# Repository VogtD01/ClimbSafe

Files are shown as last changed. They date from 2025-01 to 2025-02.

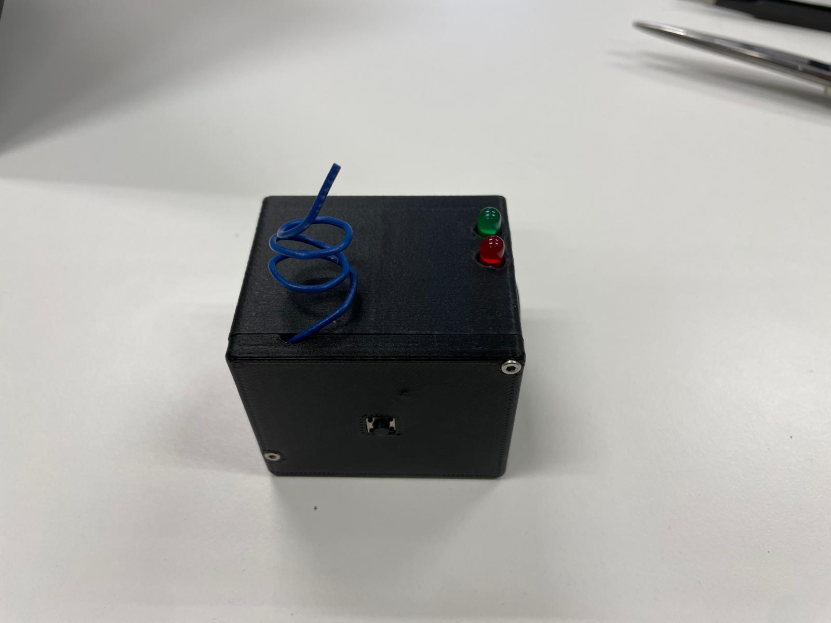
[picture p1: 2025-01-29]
Präsentation_Diagramme/Bilder/IMG-20250129-WA0006.jpg

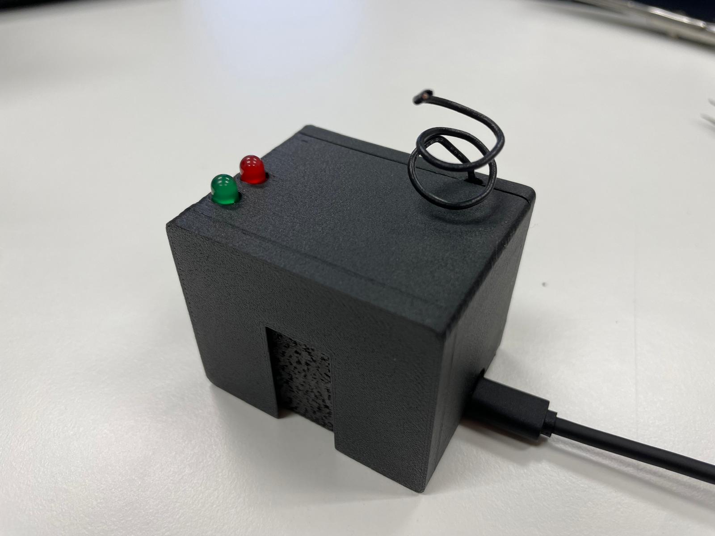
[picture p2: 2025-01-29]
Präsentation_Diagramme/Bilder/IMG-20250129-WA0011.jpg

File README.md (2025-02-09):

## Climbsafe 

ClimbSafe ist ein innovatives Sicherheitssystem für das Mehrseillängenklettern, das mithilfe von zwei ESP32-Mikrocontrollern und einem LoRa-Funkmodul eine zuverlässige Kommunikation zwischen Kletterpartnern ermöglicht. Zusätzlich integriert das System einen IMU-Sensor zur Sturzerkennung, um die Sicherheit beim Klettern zu verbessern.

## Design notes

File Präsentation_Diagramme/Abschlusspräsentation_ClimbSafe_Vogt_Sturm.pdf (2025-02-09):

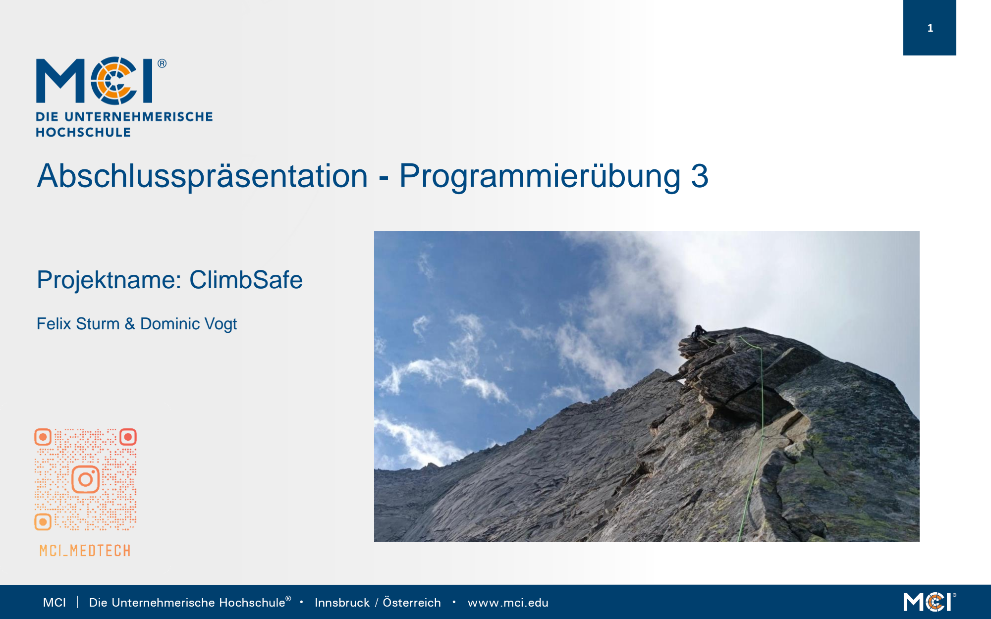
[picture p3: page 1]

1

# Abschlusspräsentation - Programmierübung 3

## Projektname: ClimbSafe

Felix Sturm & Dominic Vogt

2

## Ablauf - Mehrseillängenklettern

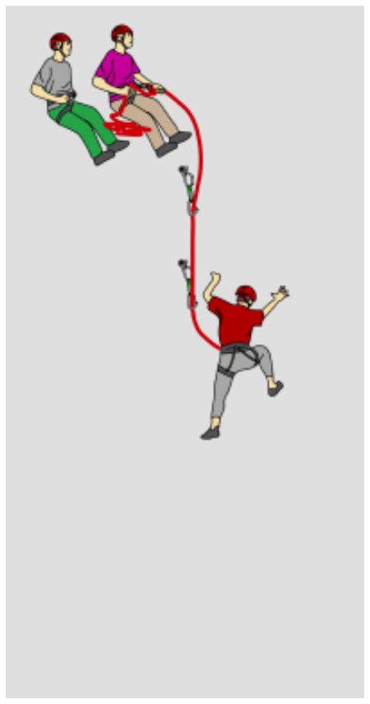
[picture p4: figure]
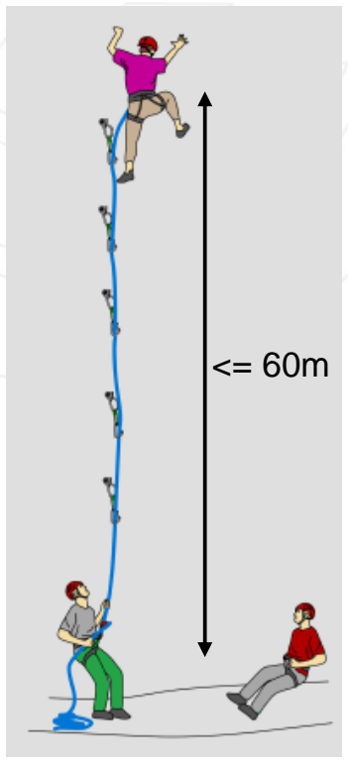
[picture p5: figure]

Vorstieg | Nachstieg
- Vorstieg

− Person 1 klettert
− Person 2 sichert Person 1
- Standplatzbau

− Person 1 baut Standplatz

- Nachstieg

− Person 1 sichert Person 2 − Person 2 klettert

3

## Problem - Mehrseillängenklettern

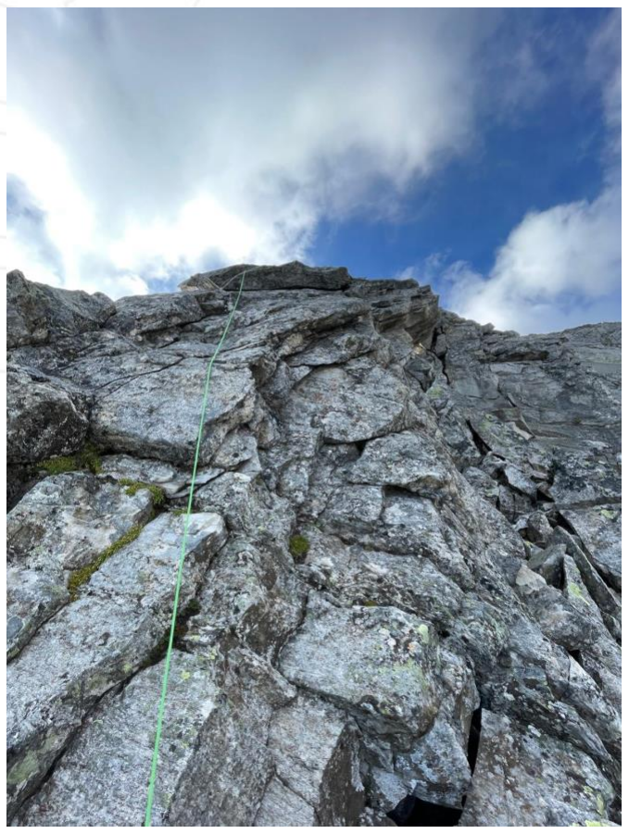
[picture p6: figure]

- Kommunikation eingeschränkt

− Überhang
− Nebel
− Wind
− …
- Bisherige Lösung:

Seilziehen

- Neue Lösung:

− Einfaches Kommunikationssystem mit Button, Piezo und LEDs

## Problem - Lösungsansatz

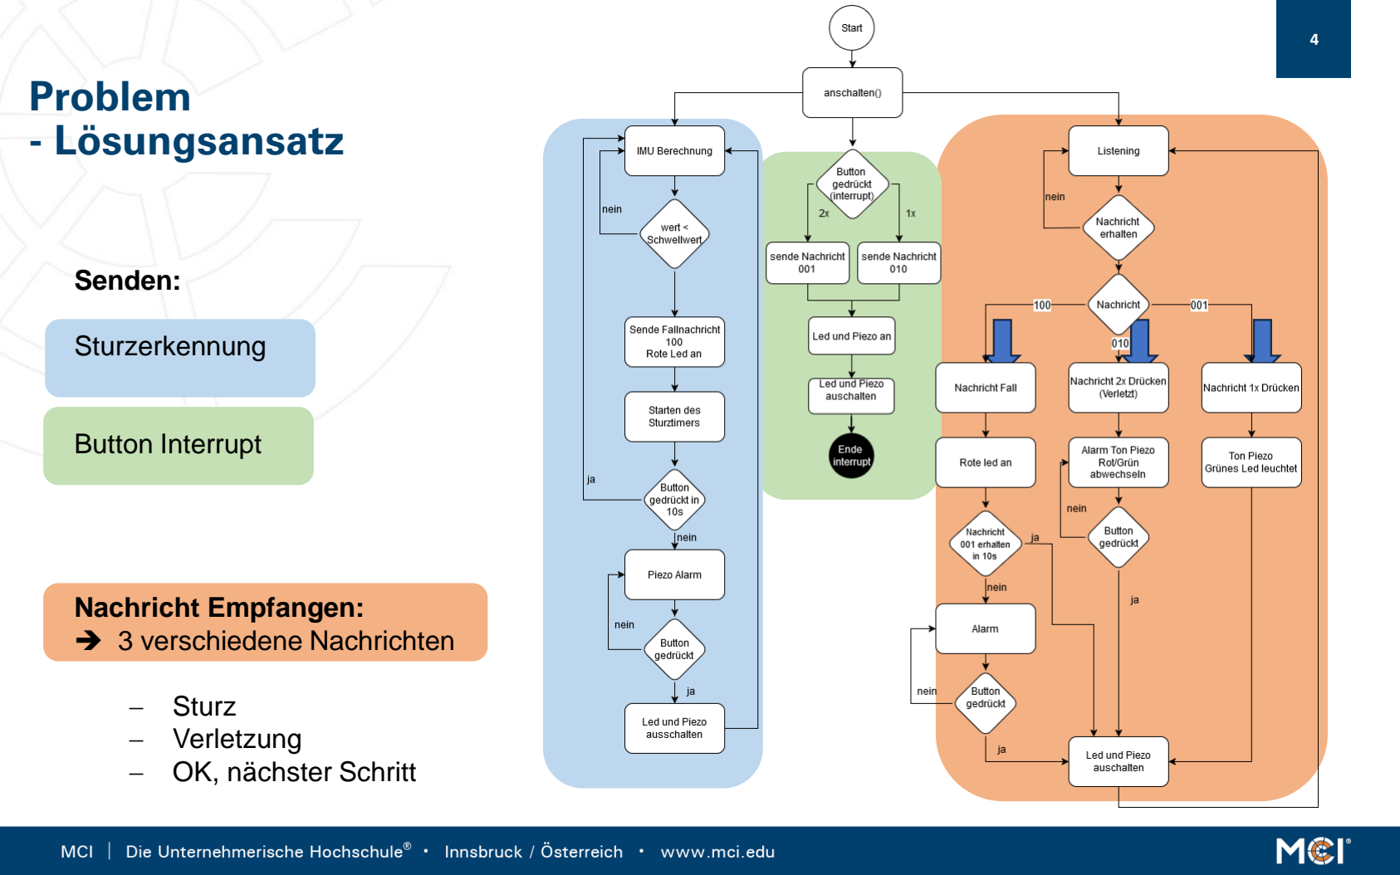
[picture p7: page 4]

4

Senden:

Sturzerkennung

Button Interrupt

Nachricht Empfangen: ➔ 3 verschiedene Nachrichten − Sturz − Verletzung − OK, nächster Schritt

# Systemübersicht

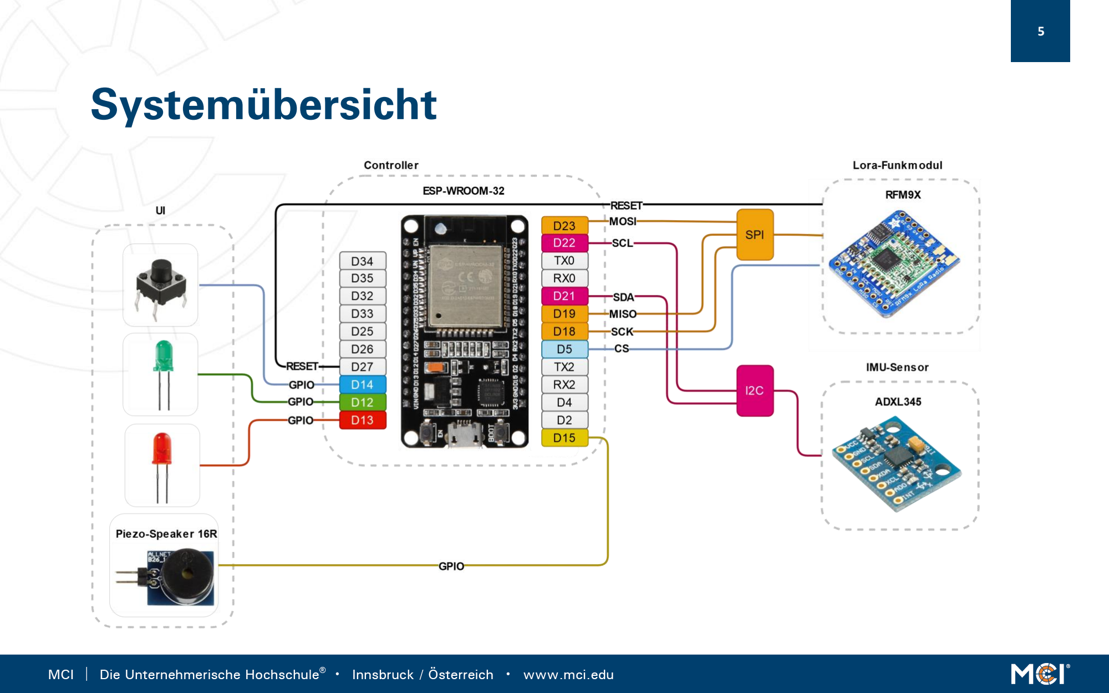
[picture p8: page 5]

5

6

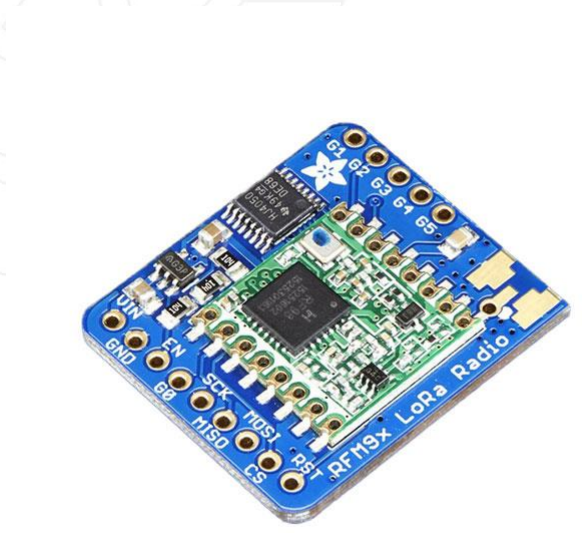
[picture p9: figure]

## - Drahtlose Kommunikationstechnologie

## - Große Reichweite, bis zu 20km (je nach Antenne) - geringer Energieverbrauch

## - Nur geringe Datenmengen

## - Frequenzbereich 433 MHz

# LoRa -> „Long Range“

# Projektumsetzung

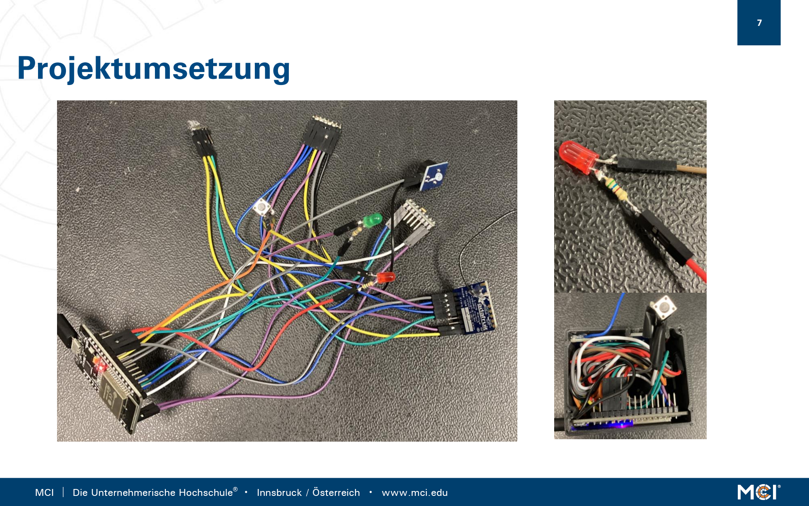
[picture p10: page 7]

7

# Prototyp

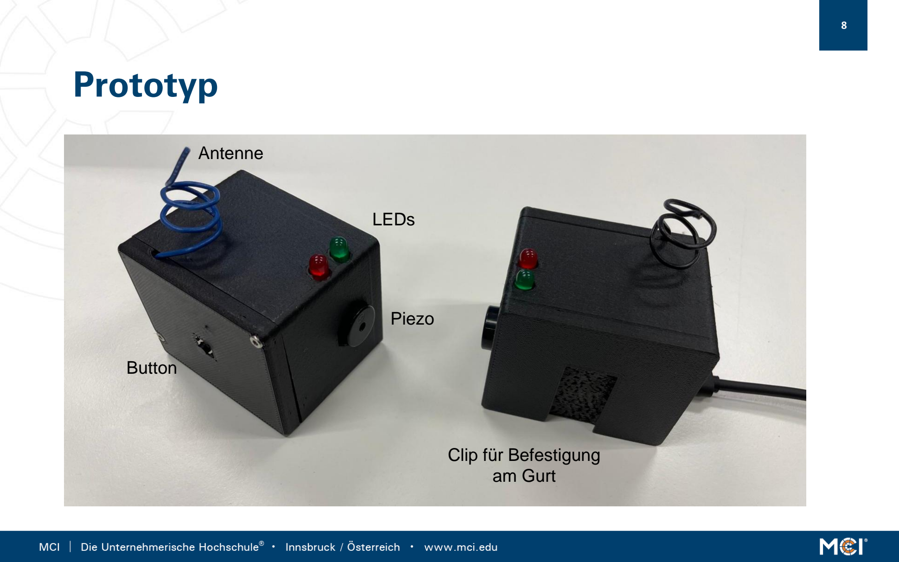
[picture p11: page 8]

8

Clip für Befestigung
am Gurt

LEDs

Button

Antenne

Piezo

# Video

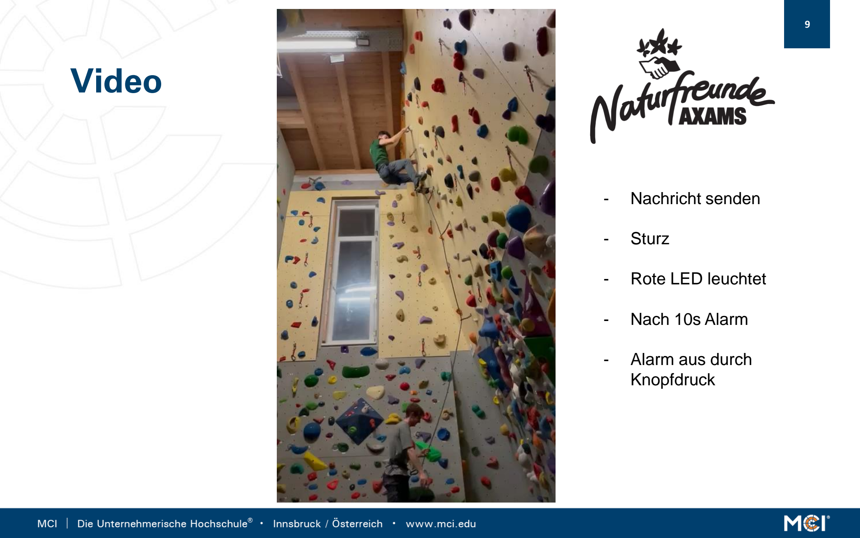
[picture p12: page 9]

9

- Nachricht senden
- Sturz
- Rote LED leuchtet
- Nach 10s Alarm
- Alarm aus durch
Knopfdruck

10

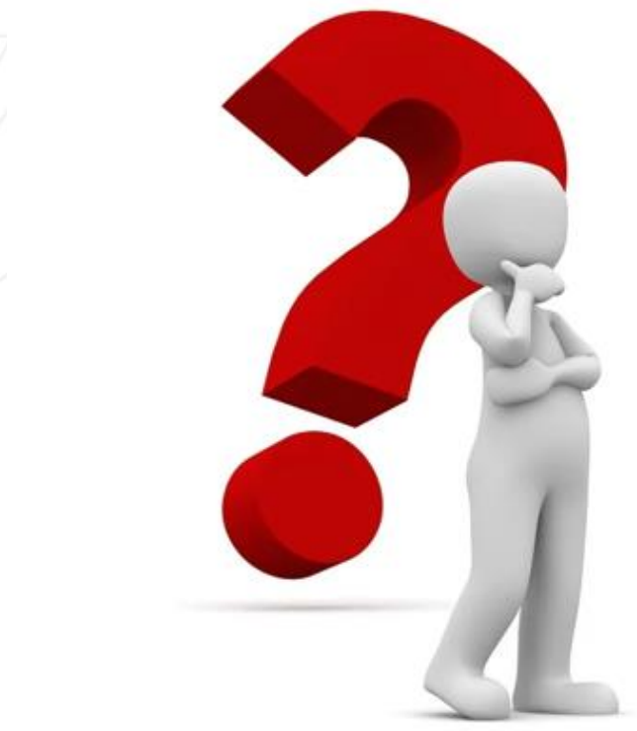
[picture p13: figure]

11

(1) https://www.google.com/url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 (https://www.google.com/url?psig=AOvVaw3JSOvj9xdNumKLQUDvxugZ&cd=vfe&opi=89978449)
(2) https://www.vdiffclimbing.com/multipitch/

# Quellen

12

## (1) Bill of Materials (BOM)

## (2) Softwarearchitektur – Komponentendiagramm

## (3) Softwarearchitektur – Activity Diagramm

## (4) Code

## (5) CAD - Konstruktion

# Anhang

13

# Bill of materials

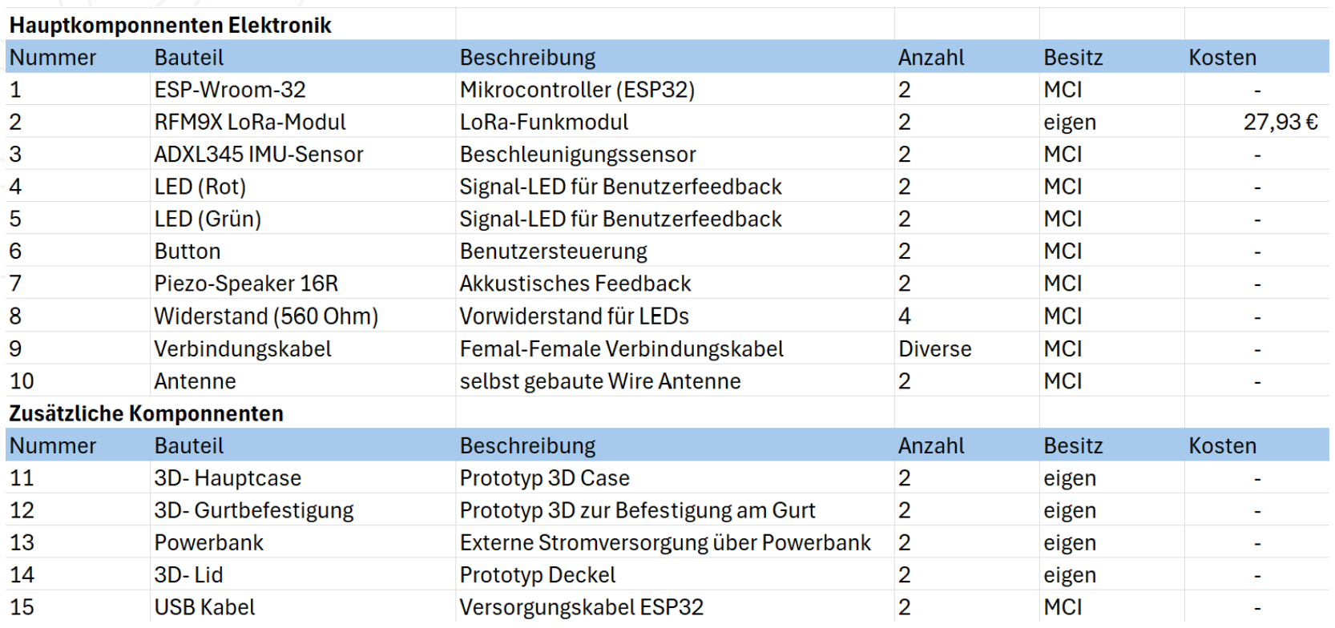
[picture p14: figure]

14

## Softwarearchitektur

Komponentendiagramm

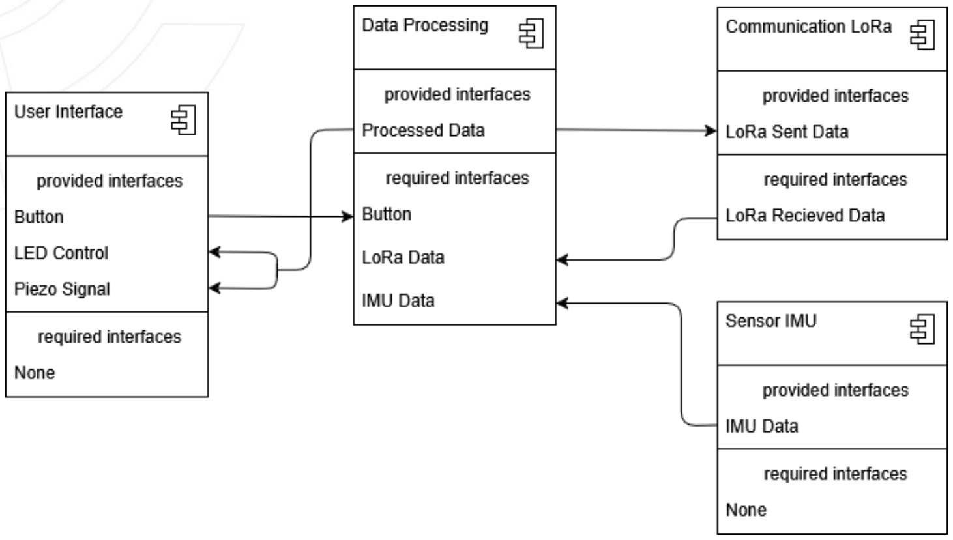
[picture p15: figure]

## Softwarearchitektur

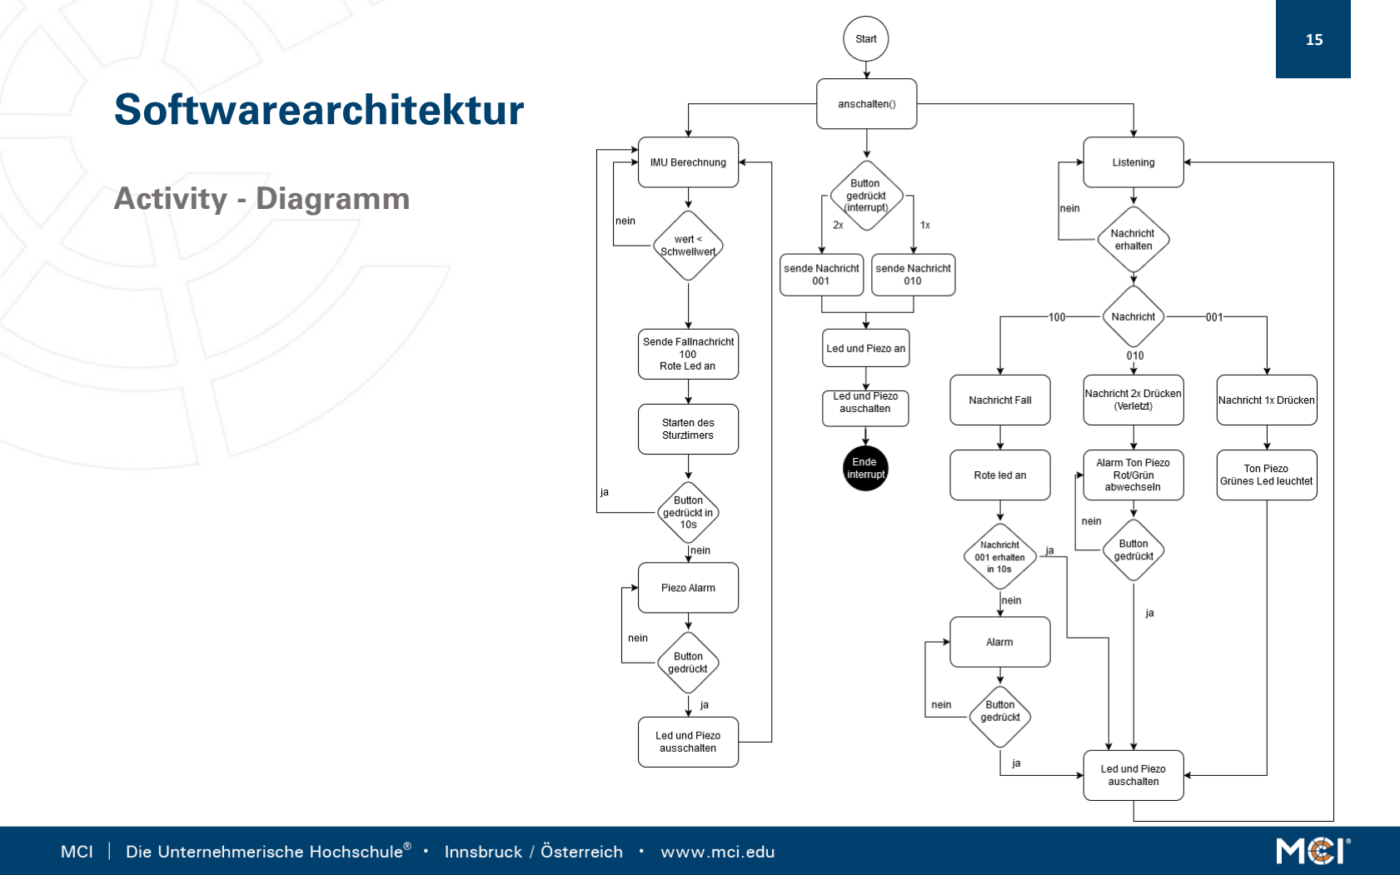
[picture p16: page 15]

15

Activity

- Diagramm

16

# Code

Verwendete Bibliotheken:

- | ADXL345_I2C | https://github.com/DFRobot/micropython-dflib/tree/master
- | Adafruit_CircuitPython_RFM9x | https://github.com/adafruit/Adafruit_CircuitPython_RFM9x

Bausteingruppen:

- Button_test
- IMU_Sturzerkennung
- Piezo_Test
- PWM_Test_Debugging

Aufbau ClimbSafe:

− | main.py | Hauptprogramm
− | functions.py | ausgelagerte Funktionen
− | status.py | Variable Fall Status
− | ADXL345.py | IMU-Bibliothek
− | adafruit_rfm9x.py | LoRa-Bibliothek

# CAD

# - Konstruktion

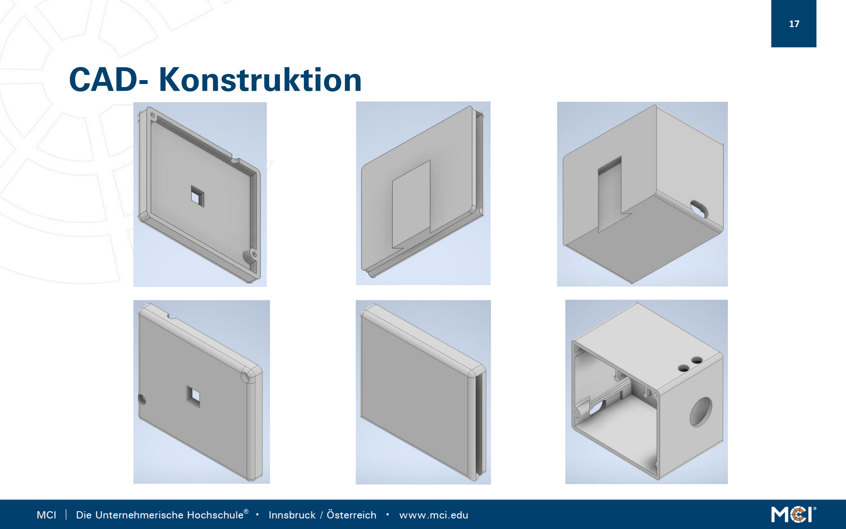
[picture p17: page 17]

17

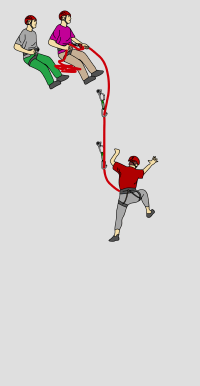
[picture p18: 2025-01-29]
Präsentation_Diagramme/Bilder/sport-multipitch-9.png

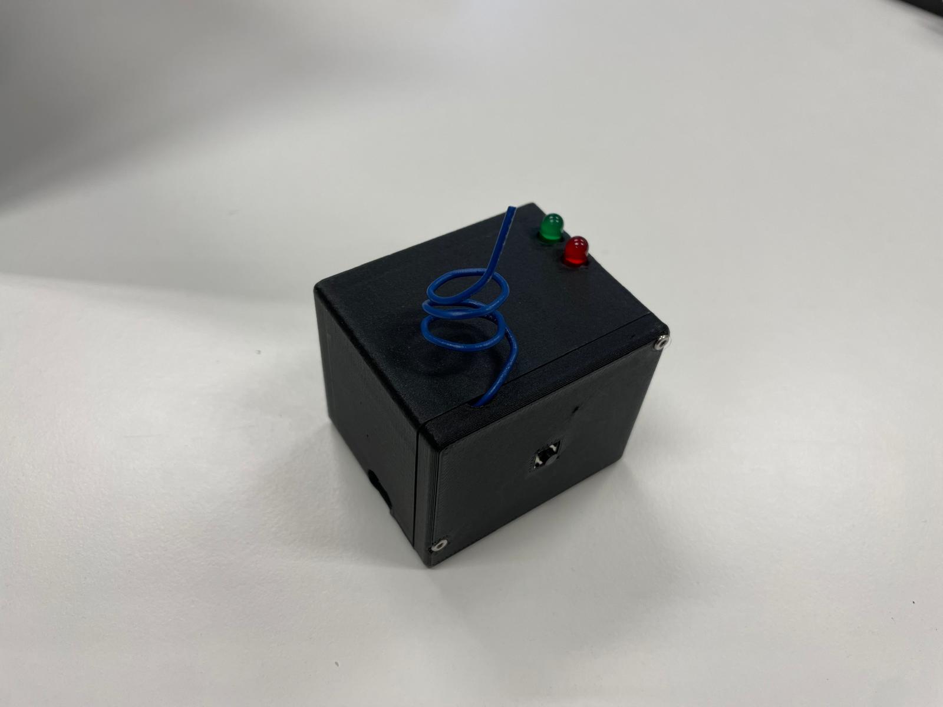
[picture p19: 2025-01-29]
Präsentation_Diagramme/Bilder/IMG-20250129-WA0010.jpg

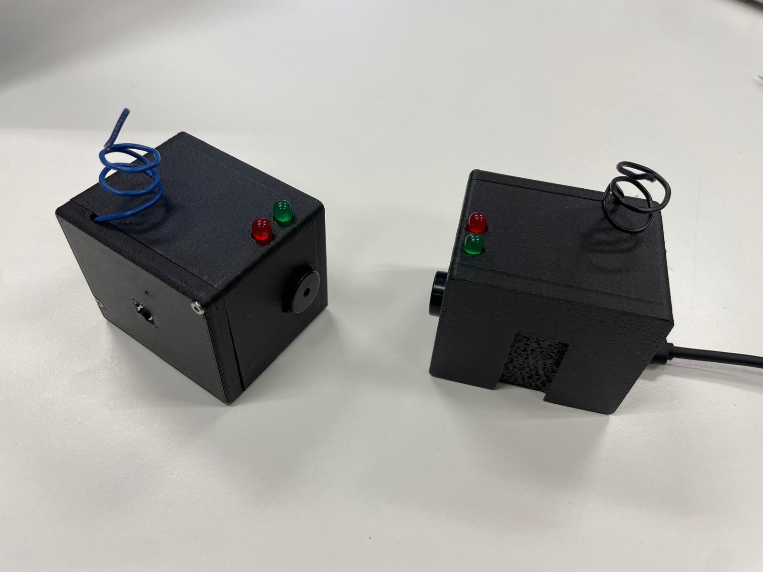
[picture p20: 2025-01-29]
Präsentation_Diagramme/Bilder/IMG-20250129-WA0012.jpg

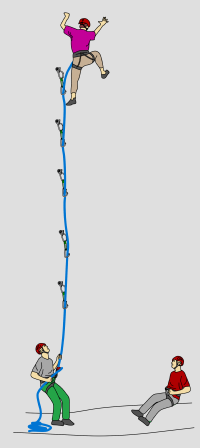
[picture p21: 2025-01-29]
Präsentation_Diagramme/Bilder/sport-multipitch-7.png

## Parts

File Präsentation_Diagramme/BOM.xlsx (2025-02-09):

Bill of Materials: ClimbSave
Hauptkomponnenten Elektronik
Nummer | Bauteil | Beschreibung | Anzahl | Besitz | Kosten
1 | ESP-Wroom-32 | Mikrocontroller (ESP32) | 2 | MCI | -
2 | RFM9X LoRa-Modul | LoRa-Funkmodul | 2 | eigen | 27.93 €
3 | ADXL345 IMU-Sensor | Beschleunigungssensor | 2 | MCI | -
4 | LED (Rot) | Signal-LED für Benutzerfeedback | 2 | MCI | -
5 | LED (Grün) | Signal-LED für Benutzerfeedback | 2 | MCI | -
6 | Button | Benutzersteuerung | 2 | MCI | -
7 | Piezo-Speaker 16R | Akkustisches Feedback | 2 | MCI | -
8 | Widerstand (560 Ohm) | Vorwiderstand für LEDs | 4 | MCI | -
9 | Verbindungskabel | Femal-Female Verbindungskabel | Diverse | MCI | -
10 | Antenne | selbst gebaute Wire Antenne | 2 | MCI | -
Zusätzliche Komponnenten
Nummer | Bauteil | Beschreibung | Anzahl | Besitz | Kosten
11 | 3D- Hauptcase | Prototyp 3D Case | 2 | eigen | -
12 | 3D- Gurtbefestigung | Prototyp 3D zur Befestigung am Gurt | 2 | eigen | -
13 | Powerbank | Externe Stromversorgung über Powerbank | 2 | eigen | -
14 | 3D- Lid | Prototyp Deckel | 2 | eigen | -
15 | USB Kabel | Versorgungskabel ESP32 | 2 | MCI | -

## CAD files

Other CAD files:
CAD_Konstruktion/Case.ipt
CAD_Konstruktion/Lid.ipt
CAD_Konstruktion/belt_clip.ipt

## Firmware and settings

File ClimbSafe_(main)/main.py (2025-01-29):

from machine import SPI, Pin, PWM, I2C, Timer
from adafruit_rfm9x import *
from ADXL345 import ADXL345_I2C
import time
import functions as f # Importiere die ausgelagerten Funktionen
import status # Importiere die ausgelagerten Statusvariablen

# Lora Konfiguration
CS = Pin(5, Pin.OUT) # Chip-Select-Pin
RESET = Pin(27, Pin.OUT) # Reset-Pin
spi = SPI(2, baudrate=1000000, polarity=0, phase=0, bits=8, firstbit=0, sck=Pin(18), mosi=Pin(23), miso=Pin(19)) # SPI-Verbindung
RADIO_FREQ_MHZ = 433.0 # Funkfrequenz in MHz

rfm9x = RFM9x(spi, CS, RESET, RADIO_FREQ_MHZ) # Erstellung eines RFM9x-Objekts
rfm9x.tx_power = 23 # Sendeleistung auf 23 Dezibel-Milliwatt (dBm) einstellen

# IMU Konfiguration
i2c = I2C(0, scl=Pin(22), sda=Pin(21)) # I2C-Verbindung
imu = ADXL345_I2C(i2c)

# LED Konfiguration
red = Pin(13, Pin.OUT )
green = Pin(12, Pin.OUT)

# Piezo-speaker Konfiguration
piezo_pin = PWM(Pin(15))
piezo_pin.freq(1000)
piezo_pin.duty(0)

# Button Konfiguration
button = Pin(14, Pin.IN, Pin.PULL_UP)

# Initialisiere Variablen 
last_button_press_time = 0 
button_press_count = 0

fall_threshold = 0.35  # Schwellenwert für freien Fall (nahe 0 g in allen Achsen)

# Timer initialisieren
timer_debounce = Timer(0)
timer_sturz = Timer(1)

# Funktion für den Button-Interrupt
def button_pressed_handler(pin):
    """Funktion, die aufgerufen wird, wenn der Button gedrückt wird.
    
    Diese Funktion sendet eine Nachricht über das Funkmodul, wenn der Button gedrückt wird.
    Bei einem Doppelklick wird eine andere Nachricht gesendet."""

    global last_button_press_time, button_press_count

    # Prüfe, ob der Button innerhalb von 2 Sekunden erneut gedrückt wurde
    current_time = time.ticks_ms()
    if time.ticks_diff(current_time, last_button_press_time) <= 2000:
        button_press_count += 1
    else:
        button_press_count = 1

    last_button_press_time = current_time # Aktualisiere die Zeit

    # Sende entsprechende Nachricht basierend auf der Anzahl der Button-Drücke
    if button_press_count == 2:
        rfm9x.send(bytes([0b010]))
        print("Doppelklick Nachricht gesendet!")

    else:
        status.fall_detected = False
        rfm9x.send(bytes([0b001]))
        print("Button gedrückt Nachricht gesendet!")
    
    f.drücken_nachricht(red, green, piezo_pin) # Hinweis für das Sendegerät, dass der Button gedrückt wurde

# Funktion für den Button-Debounce
def debounce(pin):
    '''Funktion, um den Button-Interrupt zu entprellen.
    Diese Funktion startet einen Timer, um den Button-Interrupt zu entprellen und die Button-Pressed-Handler-Funktion aufzurufen.'''
	
    timer_debounce.init(mode=Timer.ONE_SHOT, period=200, callback=button_pressed_handler)

# Button-Interrupt hinzufügen
button.irq(trigger=Pin.IRQ_FALLING, handler=debounce)

#-------------------------------------------------------------Hauptschleife------------------------------------------------------------------------


f.anschalten(red, green, piezo_pin)  # Testfunktion für die LEDs und den Piezo-Summer

print("Waiting for packets...")

while True:
    # Empfange ein Paket mit den RFM9x-Funkmodul
    packet = rfm9x.receive()

    # Beschleunigungswerte auslesen
    x = imu.xValue / 256  # Werte in g umwandeln
    y = imu.yValue / 256
    z = imu.zValue / 256

    # Berechne die Magnitude (Betrag des Beschleunigungsvektors)
    beschleunigung = f.beschleunigungsvektor_berechnen(x, y, z)

    # Prüfe auf freien Fall anhand eines Schwellenwerts
    if beschleunigung < fall_threshold:
        
        rfm9x.send(bytes([0b100])) # Nachricht senden: "100" für freien Fall erkannt
        print("Fall detected Nachricht gesendet!")

        f.fall_sender(red, piezo_pin)  # Hinweis für das Sendegerät, dass ein Fall erkannt wurde

    # Prüfe, ob ein Paket empfangen wurde
    if packet is None:
        # Kein Paket empfangen
        print("Received nothing! Listening again...")

    else:
        # Ein Paket wurde empfangen
        print("Received (raw bytes): {0}".format(packet))

        # Paketinhalte analysieren (binäre Zustände)
        if packet[0] == 0b001:  # "001" entspricht "Button gedrückt"
            timer_sturz.deinit() # Timer stoppen um fall_nachricht_empfänger zu verhindern
            f.button_nachricht(red, green, piezo_pin)  # Hinweis für das Empfängergerät, dass der Button gedrückt wurde

        elif packet[0] == 0b100:  # "100" entspricht "Fall erkannt"
            red.value(1)

            # Timer starten, um nach 10 Sekunden eine Nachricht an den Empfänger zu senden
            timer_sturz.init(mode=Timer.ONE_SHOT, period=10000, callback=lambda t: f.fall_nachricht_empfänger(red, piezo_pin))

        elif packet[0] == 0b010:  # "010" entspricht "Doppelklick, Verletzt"
            f.verletzt_nachricht_empfänger(red, green, piezo_pin)  # Hinweis für den Empfänger, dass der Benutzer verletzt ist

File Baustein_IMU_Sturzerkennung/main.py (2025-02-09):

#main

from machine import Pin, I2C, PWM
from ADXL345 import ADXL345_I2C
import time
import math

# Initialisiere I2C und den IMU-Sensor
i2c = I2C(0, scl=Pin(22), sda=Pin(21))  # I2C-Bus initialisieren
imu = ADXL345_I2C(i2c)

# LED konfigurieren
led1 = Pin(2, Pin.OUT)

# Button konfigurieren (GPIO 14)
button = Pin(14, Pin.IN, Pin.PULL_UP)  # Pull-Up-Widerstand aktivieren

# Piezo-Lautsprecher konfigurieren (GPIO 15)
piezo = PWM(Pin(15))  # PWM-Signal für Tonerzeugung
piezo.freq(1000)  # Standardfrequenz (1 kHz)
piezo.duty(0)   # Piezo ausschalten

# Schwellenwert für freien Fall (nahe 0 g in allen Achsen)
FALL_THRESHOLD = 0.35  

# Variable, um zu speichern, ob ein freier Fall erkannt wurde
fall_detected = False

def calculate_magnitude(x, y, z):
    """Berechnet die Magnitude des Beschleunigungsvektors."""
    return math.sqrt(x**2 + y**2 + z**2)

while True:
    if not fall_detected:  # Nur prüfen, wenn freier Fall noch nicht erkannt wurde
        # Lese die Beschleunigungswerte
        x = imu.xValue / 256  
        y = imu.yValue / 256
        z = imu.zValue / 256

        # Berechne die Magnitude
        magnitude = calculate_magnitude(x, y, z)
        print("Magnitude1:", magnitude)

        # Prüfe auf freien Fall
        if magnitude < FALL_THRESHOLD:
            fall_detected = True
            led1.value(1)   # LED1 einschalten

            # Piezo-Lautsprecher dauerhaft aktivieren
            piezo.duty(512)  # 50% Duty-Cycle für hörbaren Ton

    else:
        # Überprüfe, ob der Button gedrückt wurde
        if button.value() == 0:  # Button gedrückt (LOW)
            fall_detected = False  # Reset des Fall-Detektionsstatus
            print("Reset fall detection.")
            led1.value(0)  
            piezo.duty(0) 
        else:
            print("Fall detected!")
            # Piezo-Lautsprecher für 1 Sekunde aktivieren
            piezo.duty(512)
            led1.value(1)
            time.sleep(1)
            piezo.duty(0)


    # Kurze Verzögerung, um den Sensor nicht zu überlasten
    time.sleep(0.1)

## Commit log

2025-01-10 blue pin
2025-01-10 zwischenstand vor imu
2025-01-10 imu funktioniert
2025-01-12 # Initialisiere Variablen für den Button-Interrupt hat gefehlt deswegen fehler
2025-01-16 fall interrupt
2025-01-16 cleanen der Ordnerstruktur
2025-02-09 Diagramme+Präsentation
    [BOM.xlsx]
